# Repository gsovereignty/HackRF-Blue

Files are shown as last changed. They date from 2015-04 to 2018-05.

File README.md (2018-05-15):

##  HackRF Blue
http://hackrfblue.com
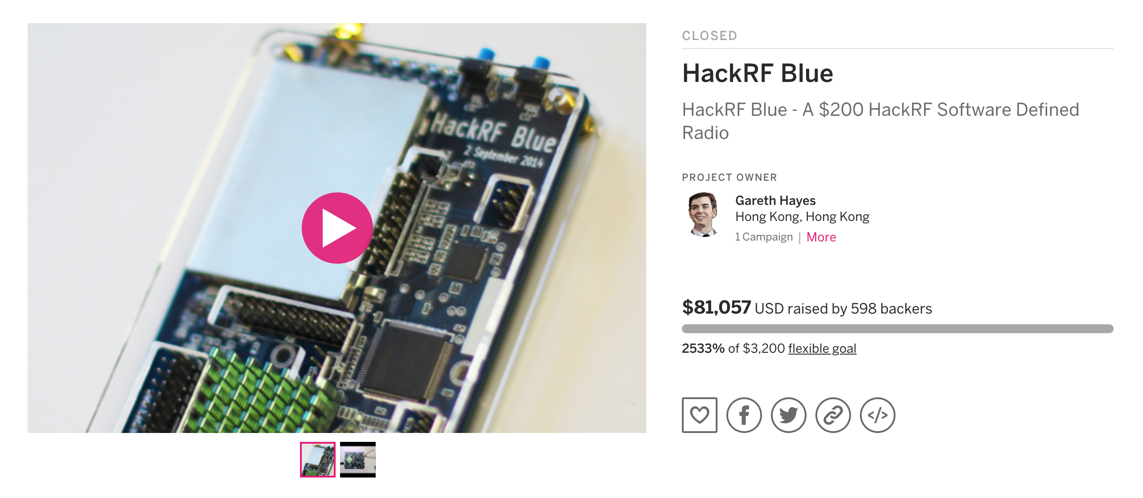
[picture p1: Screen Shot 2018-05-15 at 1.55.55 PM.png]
HackRF Blue Indiegogo


The HackRF Blue is a 0-6GHz software defined radio for RF research projects. It was funded through [Indiegogo](https://www.indiegogo.com/projects/hackrf-blue#/)

This github repo aims to reduce the cost and increase access to full-featured SDR.

This should contain everything you need to give to a PCBA manufacture to produce the HackRF Blue - what better way to reduce prices than fostering competition. 

Of course, you can work all this out from the HackRF One project itself, but you'll need to go through the process of manufacturing to get the information you need. I've gone through that process and by putting my experience here I hope to save you some time, effort, and expense. 

In the BOM you will find notes about individual parts. Some parts can safely be replaced with cheaper Chinese parts, others cannot. 

<h3>When costing the project, keep in mind the following:</h3>
<p>1. There will be a certain percentage of boards that will not work (or not work well) after manufacturing, in our case the number was 30% which would normally be stupidly high, but not for something like the HackRF. About 3% will not power up at all, another 3% will not enter DFU mode. These are 'traditional' manufacturing problems and can be easily fixed. With the HackRF though, about 20-25% will have poor RF performance due to a range of sometimes very weird issues (hint: mix in a little bit of good quality flux with the solder paste, after doing this things improved a lot). Boards with problems will need to be reworked by hand. You cannot rely on factory staff to be able to diagnose and rework something like poor RF performance unless you use a very experienced (and expensive) manufacturer. In our case, I reworked these boards myself and educated the factory staff during the process. If you are lucky, this experience will help reduce your costs, but expect at least 10% of the boards to require reworking by yourself or an RF engineer.</p>
<p>2. The BOM here does not include headers, SMA connectors, or RF shielding. These should be costed sepairately as different people want different combinations.</p>
<p>3. It is very inadvisable to embark on a manufacturing project as complicated as the HackRF if you haven't built a board yourself because when you have a factory full of staff and limited time on the SMT machine you need to be able to think fast and solve any problems very quickly under considerable pressure, in other words you need to have an intimate understanding of how the HackRF works.</p>
<p>4. It is very important that you factor the MSL level of various parts into the manufacturing process. For example if you open MSL3 parts to produce a sample board, and those parts are in tape, you can't use them for production a week later.</p>
<p>5. Don't mount the headers or RF shielding before testing. If things need to be reworked they will get in the way. Test the boards, then add these parts after, then test again.</p>

If you would like some PCBs to build your own board, contact me (garethhayes.net). I have a limited number left, if I think you might be able to pull off a manufacturing run I'll give you some.

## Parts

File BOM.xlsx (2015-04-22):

Serial | QTY | Board/Schematic Ref | Board Value | Brand | MFG Part Number | Description | Digikey Part | Replacement Part | Notes
1 | 2 | T3,T4 | RX_BALUN | Johanson Technology | 2500BL14M100T | BALUN CERAMIC CHIP WIMAX 2.5GHZ |  | HHM1711D1 (TDK) | Use brand name part only
2 | 1 | X2 | MCU_XTAL | TXC | 7V-12.000MAAE-T | CRYSTAL 12.000 MHZ 12PF SMD |  |  | Use brand name part only
3 | 1 | X3 | RTC_XTAL | Abracon | AB26TRQ-32.768KHZ-T | CRYSTAL 32.768KHZ 12.5PF SMD | 535-12051-1-ND |  | Use brand name part only
4 | 2 | T1,T2 | MIX_IN_BALUN | Anaren | B0310J50100AHF | Ultra Low Profile 0805 Balun 50 to 100 ohm Balanced | 1173-1050-1-ND |  | Use brand name part only
5 | 3 | FB1.FB2.FB3 | FILTER | Murata | BLM21PG221SN1D | FERRITE CHIP 220 OHM 2000MA 0805 |  |  | Use brand name part only
6 | 5 | L2.L3.L5.L12.L13 | 10uH | Taiyo Yuden | BRL1608T100M | INDUCTR 10UH 220MA 20% 0603 SMD |  |  | Use brand name part only
7 | 3 | Q1.Q2.Q4 | MOSFET_P | Fairchild | BSS84 | MOSFET P-CH 50V 130MA SOT-23 |  |  | Use brand name part only
8 | 1 | X1 | GSG-XTAL4PIN | AVX | CX3225GB25000D0HEQZ1 | CRYSTAL 25.000MHZ 8PF SMD |  | CX3225GB25000D0HEQCC | Use brand name part only
9 | 1 | U8 | RX_HIGHPASS_FILTER | TDK | DEA162400HT-8004B1 | FILTER HIGHPASS WLAN&BLUETOOTH |  |  | Use brand name part only
10 | 1 | Q3 | MOSFET_P | Diodes Inc. | DMP2305U-7 | MOSFET P-CH 20V 4.2A SOT-23 |  |  | Use brand name part only
11 | 1 | L7 | 6.2nH | Taiyo Yuden | HK10056N2S-T | INDUCTOR HIFREQ 6.2+/-0.3NH 0402 | 587-1514-1-ND (http://www.digikey.com/product-detail/en/0/587-1514-1-ND) |  | Use brand name part only
12 | 1 | U3 | RX_LOWPASS_FILTER | AVX | LP0603A1880ANTR | FILTER LOW PASS 1880MHZ 0603 SMD |  |  | Use brand name part only
13 | 3 | D1.D3.D9 | GSG-DIODE-TVS-BI | Murata | LXES15AAA1-100 | TVS DIODE ESD .05PF 15KV 0402 | ‎ 490-5680-1-ND (http://www.digikey.com/product-detail/en/0/490-5680-1-ND) |  | Use brand name part only
14 | 1 | U17 | MAX2837 | Maxim | MAX2837ETM+ | IC TXRX 2.3GHZ-2.7GHZ 48TQFN | MAX2837 |  | Contact Gareth Hayes if unable to find
15 | 2 | U13.U25 | MGA-81563 | Avago | MGA-81563-TR1G | 0.1-6 GHz 3 V |  |  | Use brand name part only
16 | 2 | L10.L11 | 4u7 | Taiyo Yuden | NRG4026T4R7M | INDUCTOR 4.7UH 1.6A 20% SMD |  |  | Use brand name part only
17 | 1 | U21 | TPS62410 | Texas Instruments | TPS62410DRCR | IC BUCK SYNC DUAL ADJ 0.8A 10SON |  |  | Use brand name part only
18 | 1 | Q5 | MOSFET_P | Alpha and Omega | AO3407A | MOSFET P-CH -30V -4.3A SOT23 |  |  | Use brand name part only
19 | 3 | U9.U12.U14 | SKY13317 | Skyworks | SKY13317-373LF | 20 MHz-6.0 GHz pHEMT GaAs SP3T Switch |  |  | Use brand name part only
20 | 7 | U1.U2.U5.U6.U7.U10.U11 | SKY13350 | Skyworks | SKY13350-385LF | 0.01-6.0 GHz GaAs SPDT Switch |  |  | Use brand name part only
21 | 1 | U24 | GSG-XC2C64A-7VQG100C | Xilinx | XC2C64A-7VQG100C | IC CR-II CPLD 64MCELL 100-VQFP |  |  | Use brand name part only
22 | 1 | U15 | LXES1TBCC2-004 | Murata | LXES1TBCC2-004 | ESD Suppressors 0.55pF 6V 2ch |  |  | Use brand name part only
23 | 1 | U23 | LPC4320FBD144 | NXP | LPC4320FBD144 |  |  |  | Use brand name part only
24 | 1 | U18 | MAX5864 | Maxim | MAX5864ETM+ | IC ANLG FRONT END 22MSPS 48-TQFN |  |  | Use brand name part only
25 | 1 | U19 | SI5351C | Silicon Laboratories Inc | SI5351C-B-GM | IC CLK GENERATOR 160MHZ 20QFN |  |  | Use brand name part only
26 | 1 | J1 | USB-MICRO-B | FCI | 10103592-0001LF | CONN RCPT REV MICRO USB TYPE B |  |  | Be careful with Chinese replacements. Test extensively.
27 | 1 | R3 | 22k | Panasonic | ERJ-2GEJ223X | RES 22K OHM 1/10W 5% 0402 SMD
28 | 1 | SW1 | DFU | TE Connectivity | FSMRA3JH | SWITCH TACTILE SPST-NO 0.05A 12V |  |  | Actively seek Chinese replacement
29 | 1 | SW2 | RESET | TE Connectivity | FSMRA3JH | SWITCH TACTILE SPST-NO 0.05A 12V |  |  | Actively seek Chinese replacement
30 | 6 | C41.C42.C52.C70.C90.C160 | 100pF | Murata | GRM1555C1H101JA01D | CAP CER 100PF 50V 5% NP0 0402 |  |  | Test Chinese replacements carefully
31 | 4 | C118.C157.C158.C164 | 18pF | Murata | GRM1555C1H180JA01D | CAP CER 18PF 50V 5% NP0 0402 |  |  | Test Chinese replacements carefully
32 | 2 | C15.C112 | 180pF | Murata | GRM1555C1H181JA01D | CAP CER 180PF 50V 5% NP0 0402 |  |  | Test Chinese replacements carefully
33 | 12 | C8.C21.C32.C43.C48.C51.C84.C85.C86.C94.C99.C102 | 22pF | Murata | GRM1555C1H220JA01D | CAP CER 22PF 50V 5% NP0 0402 |  |  | Test Chinese replacements carefully
34 | 33 | C1.C3.C5.C7.C10.C11.C16.C19.C22.C24.C29.C30.C33.C34.C35.C36.C37.C38.C39.C40.C45.C47.C54.C55.C56.C57.C60.C63.C65.C66.C67.C115.C125 | 33pF | Murata | GRM1555C1H330JA01D | CAP CER 33PF 50V 5% NP0 0402 |  |  | Test Chinese replacements carefully
35 | 2 | C104.C111 | 3pF | Murata | GRM1555C1H3R0CA01D | CAP CER 3PF 50V NP0 0402 |  |  | Test Chinese replacements carefully
36 | 3 | C26.C27.C116 | 47pF | Murata | GRM1555C1H470JA01D | CAP CER 47PF 50V 5% NP0 0402 |  |  | Test Chinese replacements carefully
37 | 57 | C9.C17.C18.C20.C23.C25.C28.C31.C44.C46.C49.C50.C58.C59.C61.C62.C64.C71.C73.C75.C77.C79.C81.C83.C91.C113.C119.C120C121C122C123C128C129C130C131C132C133C134C135C136C137C138C139C140C141C142C144C147C148C149C150C151C152C153C154C166C167 | 100nF | Murata | GRM155R61A104KA01D | CAP CER 0.1UF 10V 10% X5R 0402 |  |  | Test Chinese replacements carefully
38 | 3 | C97.C98.C100 | 330nF | Murata | GRM155R61A334KE15D | CAP CER 0.33UF 10V 10% X5R 0402 |  |  | Test Chinese replacements carefully
39 | 10 | C2.C4.C6.C87.C88.C89.C92.C93.C162.C163 | 10nF | Murata | GRM155R71C103KA01D | CAP CER 10000PF 16V 10% X7R 0402 |  |  | Test Chinese replacements carefully
40 | 2 | C12.C13 | 330pF | Murata | GRM155R71H331KA01D | CAP CER 330PF 50V 10% X7R 0402 |  |  | Test Chinese replacements carefully
41 | 1 | C114 | 3.3nF | Murata | GRM155R71H332KA01D | CAP CER 3300PF 50V 10% X7R 0402 |  |  | Test Chinese replacements carefully
42 | 6 | C105.C126.C127.C143.C145.C146 | 10uF | Murata | GRM21BR61A106KE19L | CAP CER 10UF 10V 10% X5R 0805 |  |  | Test Chinese replacements carefully
43 | 1 | C53 (C106) | 1uF | Taiyo Yuden | LMK105BJ105KV-F | CAP CER 1UF 10V 10% X5R 0402 |  |  | Test Chinese replacements carefully
44 | 3 | C106.C161.C171 | 1uF | Taiyo Yuden | LMK105BJ105KV-F | CAP CER 1UF 10V 10% X5R 0402 |  |  | Test Chinese replacements carefully
45 | 7 | C72.C74.C76.C78.C80.C82.C124 | 2.2uF | Taiyo Yuden | LMK105BJ225MV-F | CAP CER 2.2UF 10V 20% X5R 0402 |  |  | Test Chinese replacements carefully
47 | 1 | D4 | USBLED | Lite-On | LTST-S220KGKT | LED GREEN CLEAR RT ANG 0805 |  |  | Use original brand, replacements often cause issues
48 | 1 | D7 | VCCLED | Lite-On | LTST-S220KGKT | LED GREEN CLEAR RT ANG 0805 |  |  | Use original brand, replacements often cause issues
49 | 1 | D2 | VAALED | Lite-On | LTST-S220KRKT | LED SUPR RED CLR RT ANG 0805 |  |  | Use original brand, replacements often cause issues
50 | 1 | D6 | TXLED | Lite-On | LTST-S220KRKT | LED SUPR RED CLR RT ANG 0805 |  |  | Use original brand, replacements often cause issues
51 | 1 | D5 | RXLED | Lite-On | LTST-S220KSKT | LED YELLOW CLEAR RT ANG 0805 |  |  | Use original brand, replacements often cause issues
52 | 1 | D8 | 1V8LED | Lite-On | LTST-S220KSKT | LED YELLOW CLEAR RT ANG 0805 |  |  | Use original brand, replacements often cause issues
53 | 6 | R8.R9.R10.R13.R73.R76 | 1k | Stackpole | RMCF0402FT1K00 | RES 1K OHM 1/16W 1% 0402
54 | 4 | R14.R15.R16.R17 | 4k7 | Stackpole | RMCF0402FT4K70 | RES 4.7K OHM 1/16W 1% 0402
55 | 26 | R5.R6.R7.R11.R12.R24.R29.R36.R37.R41.R48.R49.R51.R52.R54.R59.R63.R64.R65.R66.R67.R68.R85.R93.R104.R105 | 10k | Stackpole | RMCF0402JT10K0 | RES 10K OHM 1/16W 5% 0402 SMD
56 | 22 | R19.R30.R31.R32.R33.R34.R77.R78.R79.R80.R81.R86.R87.R88.R89.R90.R91.R94.R96.R98.R99.R100 | 39 | Stackpole | RMCF0402JT39R0 | RES 39 OHM 1/16W 5% 0402 SMD
57 | 1 | C14 | 8p2 | Taiyo Yuden | UMK105CG8R2DV-F | CAP CER 8.2PF 50V NP0 0402
59 | 1 | R69 | 12k | Rohm | MCR01MRTF1202 | RES 12.0K OHM 1/16W 1% 0402 SMD
60 | 2 | R46.R55 | 162k | Stackpole | RMCF0402FT162K | RES TF 1/16W 162K OHM 1% 0402
61 | 1 | R47 | 330k | Stackpole | RMCF0402FT330K | RES TF 1/16W 330K OHM 1% 0402
62 | 1 | R4 | 51k | Stackpole | RMCF0402FT51K0 | RES TF 51K OHM 1% 0.0625W 0402
63 | 1 | R56 | 715k | Stackpole | RMCF0402FT715K | RES TF 1/16W 715K OHM 1% 0402
64 | 4 | R18.R27.R28.R74 | 1k8 | Stackpole | RMCF0402JT1K80 | RES TF 1.8K OHM 5% 1/16W 0402
65 | 6 | R1.R2.R25.R26.R72.R75 | 470 | Stackpole | RMCF0402JT470R | RES TF 1/16W 470 OHM 5% 0402
66 | 7 | R20.R21.R22.R23.R57.R58.R62 | 0 | Stackpole | RMCF0402ZT0R00 | RES 0.0 OHM 1/16W 0402 SMD
67 | 1 | U20 | W25Q80BV | Winbond | W25Q80BVSSIG | IC FLASH 8MBIT 8SOIC |  | W25Q80DVSNIG (Diff. Footprint) | Do NOT use Adesto replacement, issues with 4320
 | 1 | U4 | RFFC5072 | RFMD |  |  |  |  | Purchase from RFMD (Spencer Gilden)
